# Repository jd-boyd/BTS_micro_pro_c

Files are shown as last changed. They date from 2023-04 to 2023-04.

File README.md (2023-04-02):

# BTS_micro_pro_c

## ABOUT

MCU board, mostly with pinout of Arduino Nano Pro, shows up as Leonardo, has USB-C connector.

## LICENSE

* Licensed under CERN-OHL-P v2 or later
* See LICENSE file
* See https://ohwr.org/project/cernohl/wikis/uploads/8a6b5d01f71c207c49493e4d114d61e6/cern_ohl_p_v2_howto.pdf for summary.

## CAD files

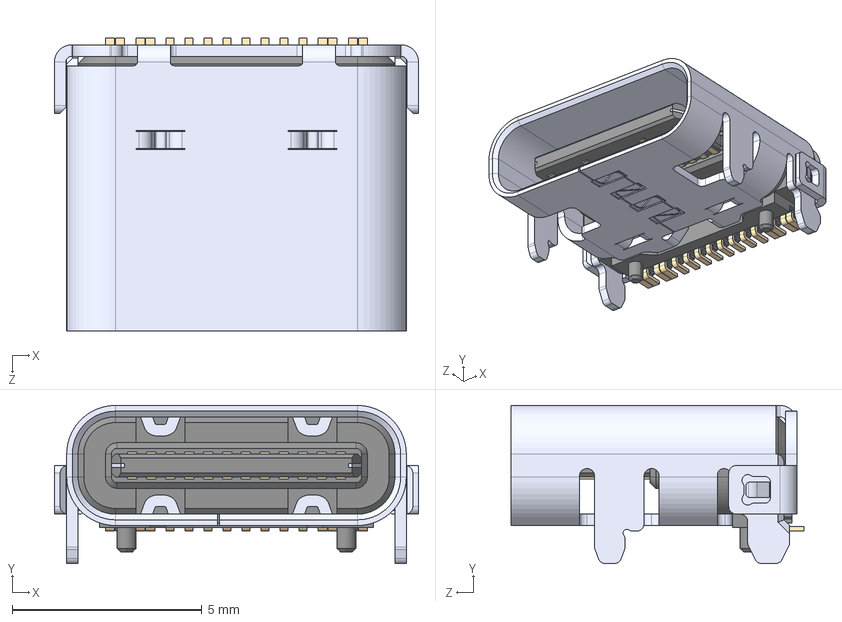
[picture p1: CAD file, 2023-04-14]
snapeda/USB4105-GF-A/USB4105-GF-A.step
9.58 x 4.16 x 7.71 mm

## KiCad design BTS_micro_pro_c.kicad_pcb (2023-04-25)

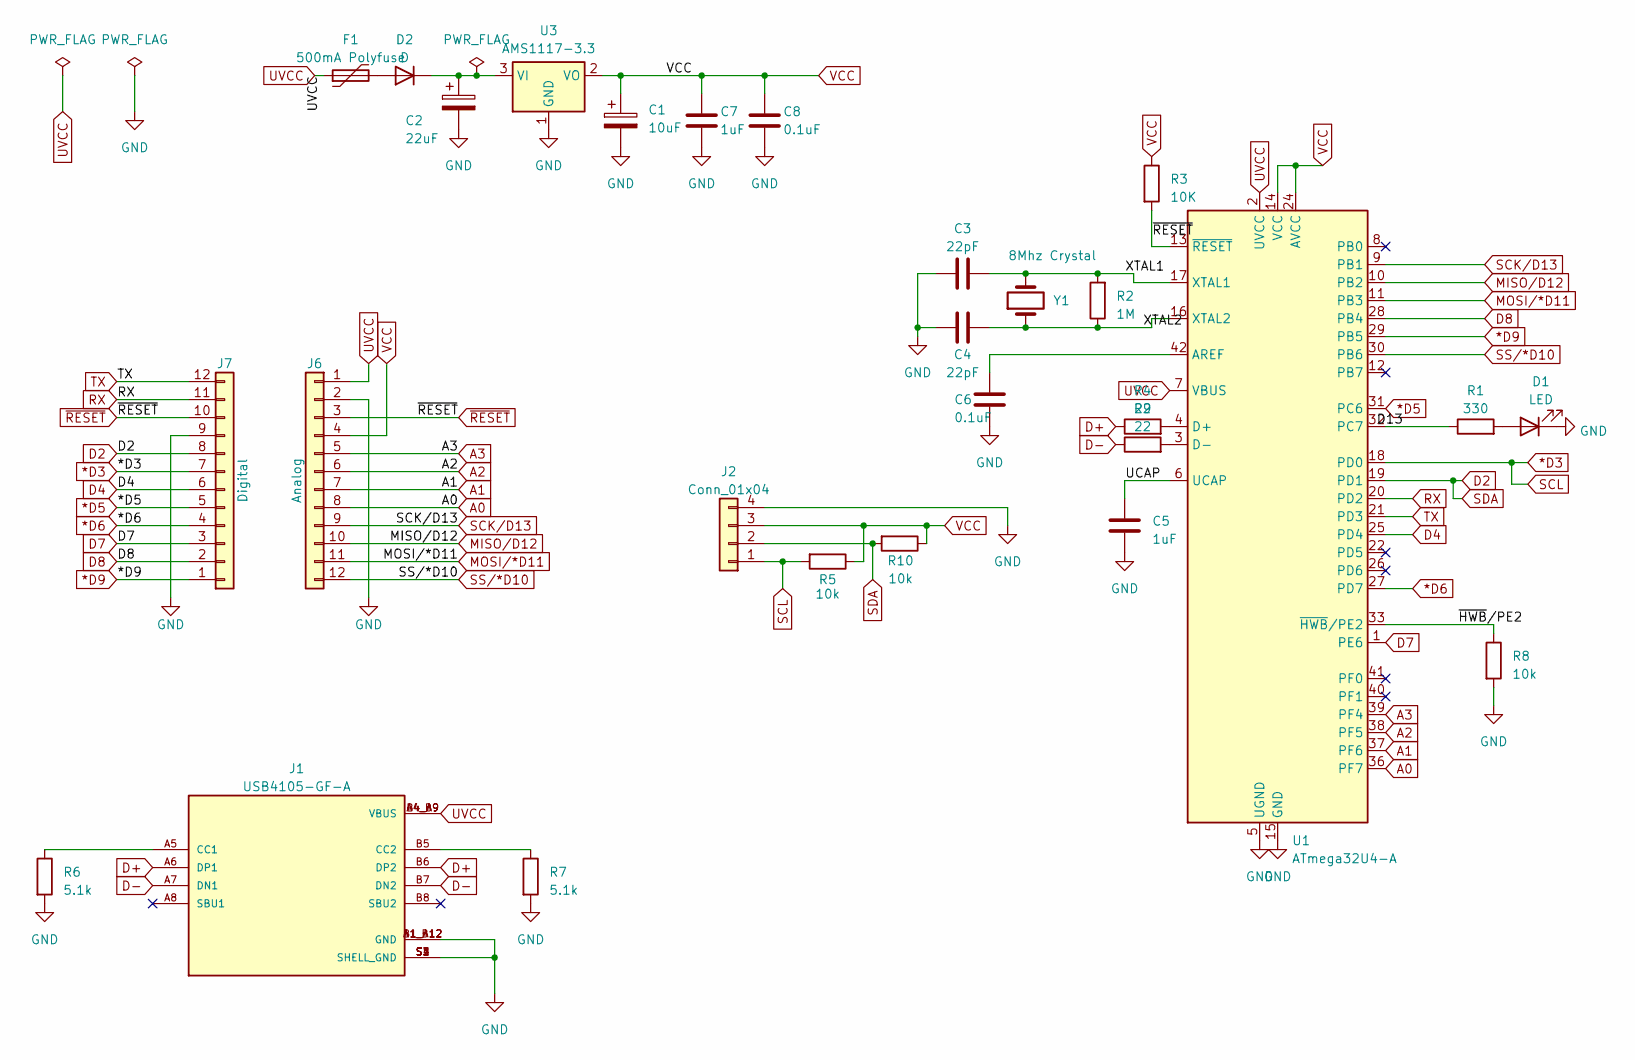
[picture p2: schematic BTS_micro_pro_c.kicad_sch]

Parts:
C1: 10uF; C_0402_1005Metric
C2: 22uF; C_0402_1005Metric
C3, C4: 22pF; C_0402_1005Metric
C5, C7: 1uF; C_0402_1005Metric
C6, C8: 0.1uF; C_0402_1005Metric
D1: LED; LED_0402_1005Metric
D2: D; D_0402_1005Metric; LCSC C316041
F1: 500mA Polyfuse; Fuse_0805_2012Metric; LCSC C135331
J1: USB4105-GF-A; GCT_USB4105-GF-A; PARTREV A3; LCSC C165948
J2: Conn_01x04; JST_SH_BM04B-SRSS-TB_1x04-1MP_P1.00mm_Vertical; LCSC C495539
J6: Analog; PinHeader_1x12_P2.54mm_Vertical
J7: Digital; PinHeader_1x12_P2.54mm_Vertical
R1: 330; R_0402_1005Metric
R2: 1M; R_0402_1005Metric
R3: 10K; R_0402_1005Metric
R4, R9: 22; R_0402_1005Metric
R5, R8, R10: 10k; R_0402_1005Metric
R6, R7: 5.1k; R_0402_1005Metric
U1: ATmega32U4-A; QFN-44-1EP_7x7mm_P0.5mm_EP5.2x5.2mm; LCSC C112161
U3: AMS1117-3.3; SOT-23-3; LCSC C5446
Y1: 8Mhz Crystal; Crystal_SMD_3225-2Pin_3.2x2.5mm; LCSC C409345

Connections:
*D3: J2.1, J7.7, R5.2, U1.18 (PD0)
*D5: J7.5, U1.31 (PC6)
*D6: J7.4, U1.27 (PD7)
*D9: J7.1, U1.29 (PB5)
/D13: R1.1, U1.32 (PC7)
/UCAP: C5.1, U1.6 (UCAP)
/XTAL1: C3.2, R2.2, U1.17 (XTAL1), Y1.2
/XTAL2: C4.1, R2.1, U1.16 (XTAL2), Y1.1
/~HWB/PE2: R8.1, U1.33 (~HWB/PE2)
A0: J6.8, U1.36 (PF7)
A1: J6.7, U1.37 (PF6)
A2: J6.6, U1.38 (PF5)
A3: J6.5, U1.39 (PF4)
D2: J2.2, J7.8, R10.2, U1.19 (PD1)
D4: J7.6, U1.25 (PD4)
D7: J7.3, U1.1 (PE6)
D8: J7.2, U1.28 (PB4)
D+: J1.A6 (DP1), J1.B6 (DP2), R4.1
D-: J1.A7 (DN1), J1.B7 (DN2), R9.1
GND: C1.2, C2.2, C3.1, C4.2, C5.2, C6.2, C7.2, C8.2, D1.1 (K), J1.A1_B12 (GND), J1.B1_A12 (GND), J1.S1 (SHELL_GND), J1.S2 (SHELL_GND), J1.S3 (SHELL_GND), J1.S4 (SHELL_GND), J2.4, J6.2, J7.9, R6.2, R7.2, R8.2, U1.5 (UGND), U1.15 (GND), U1.23 (GND), U1.35 (GND), U1.43 (GND), U3.1 (GND)
MISO/D12: J6.10, U1.10 (PB2)
MOSI/*D11: J6.11, U1.11 (PB3)
unnamed: D1.2 (A), R1.2
unnamed: D2.2 (A), F1.2
unnamed: C2.1, D2.1 (K), U3.3 (VI)
unnamed: J1.A5 (CC1), R6.1
unnamed: J1.B5 (CC2), R7.1
unnamed: C6.1, U1.42 (AREF)
unnamed: R4.2, U1.4 (D+)
unnamed: R9.2, U1.3 (D-)
RX: J7.11, U1.20 (PD2)
SCK/D13: J6.9, U1.9 (PB1)
SS/*D10: J6.12, U1.30 (PB6)
TX: J7.12, U1.21 (PD3)
UVCC: F1.1, J1.A4_B9 (VBUS), J1.B4_A9 (VBUS), J6.1, U1.2 (UVCC), U1.7 (VBUS)
VCC: C1.1, C7.1, C8.1, J2.3, J6.4, R3.1, R5.1, R10.1, U1.14 (VCC), U1.24 (AVCC), U1.34 (VCC), U1.44 (AVCC), U3.2 (VO)
~RESET: J6.3, J7.10, R3.2, U1.13 (~RESET)

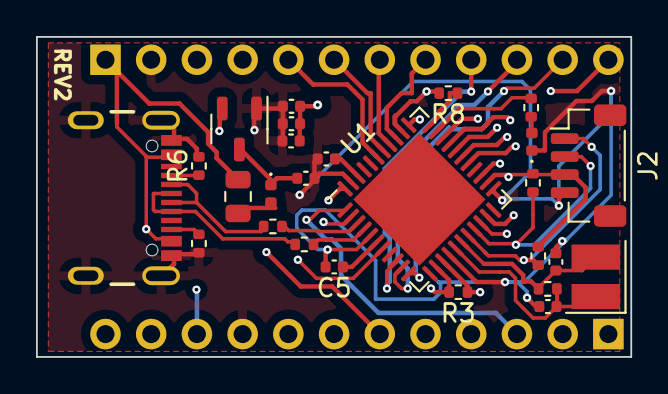
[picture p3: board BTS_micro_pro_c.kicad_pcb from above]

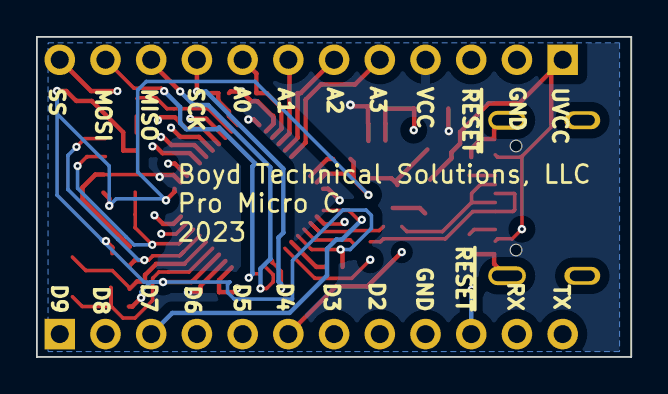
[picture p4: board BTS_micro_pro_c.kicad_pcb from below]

Board: 4 copper layers, 33.0 x 17.8 mm, 28 parts (2 on the bottom side), 37 nets.

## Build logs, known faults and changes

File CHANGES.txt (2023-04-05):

Modifications made by Licensee and/or Licensor (see section 3.4.b in the CERN OHL)

V0.1: Initial release

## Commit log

2023-04-02 Initial import of KiCAD project.
    [BTS_micro_pro_c.kicad_pcb, BTS_micro_pro_c.kicad_sch]
2023-04-08 More progress.
    [BTS_micro_pro_c.kicad_sch]
2023-04-11 Schematic potentially done, needs footprints assigned though.
    [BTS_micro_pro_c.kicad_pcb, BTS_micro_pro_c.kicad_sch]
2023-04-14 Finish rev1.
    [BTS_micro_pro_c.kicad_pcb, BTS_micro_pro_c.kicad_sch, USB4105-GF-A.step]
2023-04-21 Start rev 2.
    In schematic, add USB resistors, put back I2C port.
    Also, fix rotation issue that JLCPCB DFM picked up.
    [BTS_micro_pro_c.kicad_sch]
2023-04-25 Update project to rev 2.
    This includes new I2C connector (STEMMA QT), fixed missing resistors on USB, change to easier to route osc.
    Also includes custominng some footprints for space concerns.
    [BTS_micro_pro_c.kicad_pcb, BTS_micro_pro_c.kicad_sch]
